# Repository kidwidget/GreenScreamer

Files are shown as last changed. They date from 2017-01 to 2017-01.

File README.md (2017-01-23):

# GreenScreamer
Guitar Effects Pedal
Uses Kicad
Has extra mounting holes for all capacitors, resistors, and diodes that effect tone. This is so you can solder in female pin headers to test various combinations before commiting. Bottom layer is only for ground plane. It can be omitted if you are making a single sided PCB. This will need jumper wires, refer to picture of finished product.

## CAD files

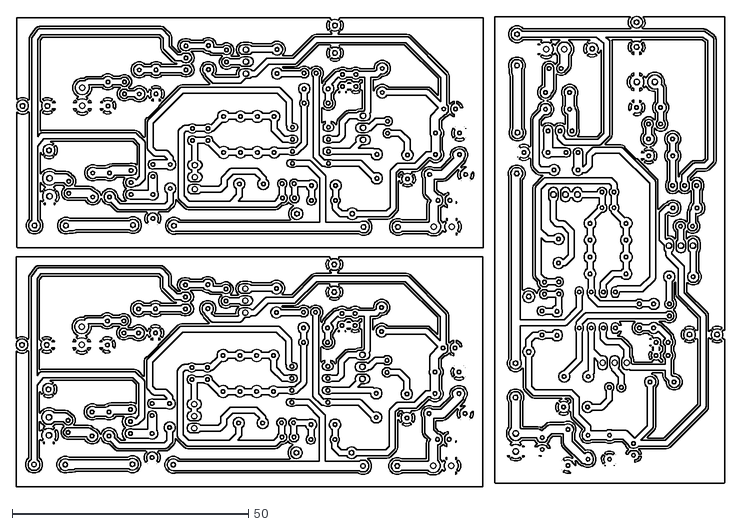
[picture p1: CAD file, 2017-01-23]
GreenScreamerGraphics/DXF/-B.Cu.dxf
149.9 x 99.5

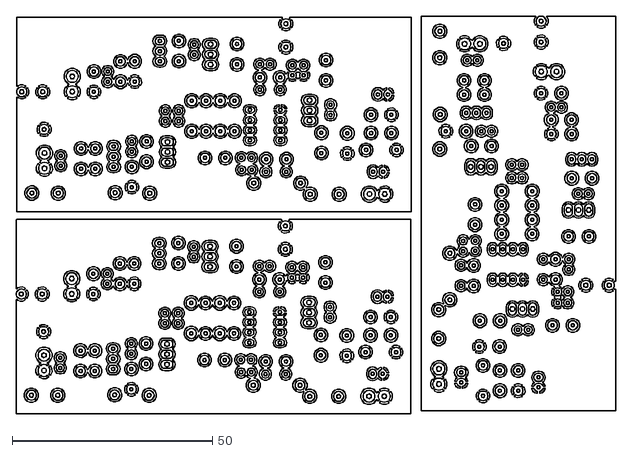
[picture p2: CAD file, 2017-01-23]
GreenScreamerGraphics/DXF/-F.Cu.dxf
149.9 x 99.5

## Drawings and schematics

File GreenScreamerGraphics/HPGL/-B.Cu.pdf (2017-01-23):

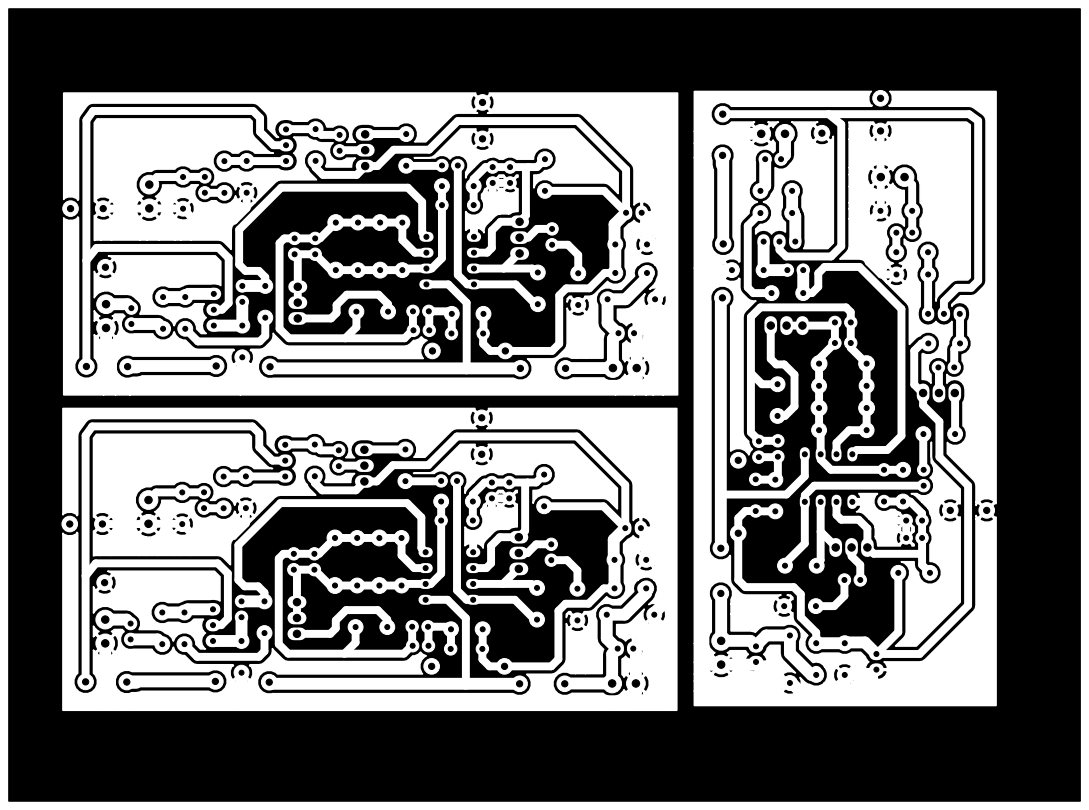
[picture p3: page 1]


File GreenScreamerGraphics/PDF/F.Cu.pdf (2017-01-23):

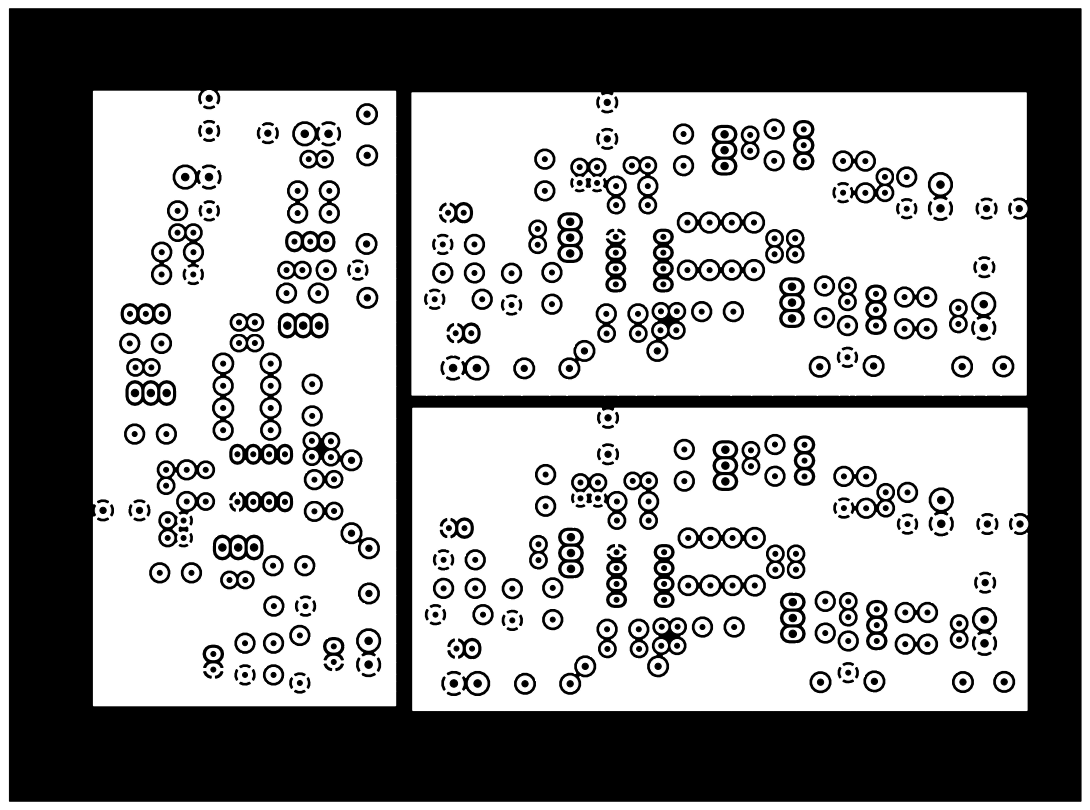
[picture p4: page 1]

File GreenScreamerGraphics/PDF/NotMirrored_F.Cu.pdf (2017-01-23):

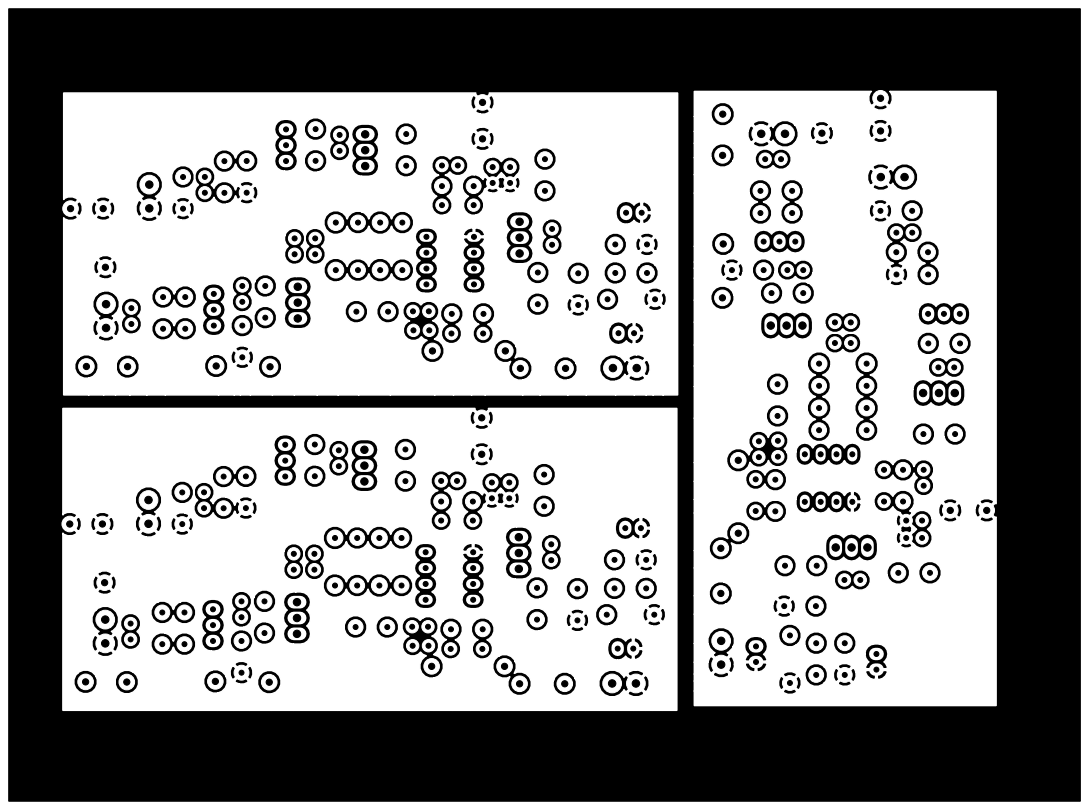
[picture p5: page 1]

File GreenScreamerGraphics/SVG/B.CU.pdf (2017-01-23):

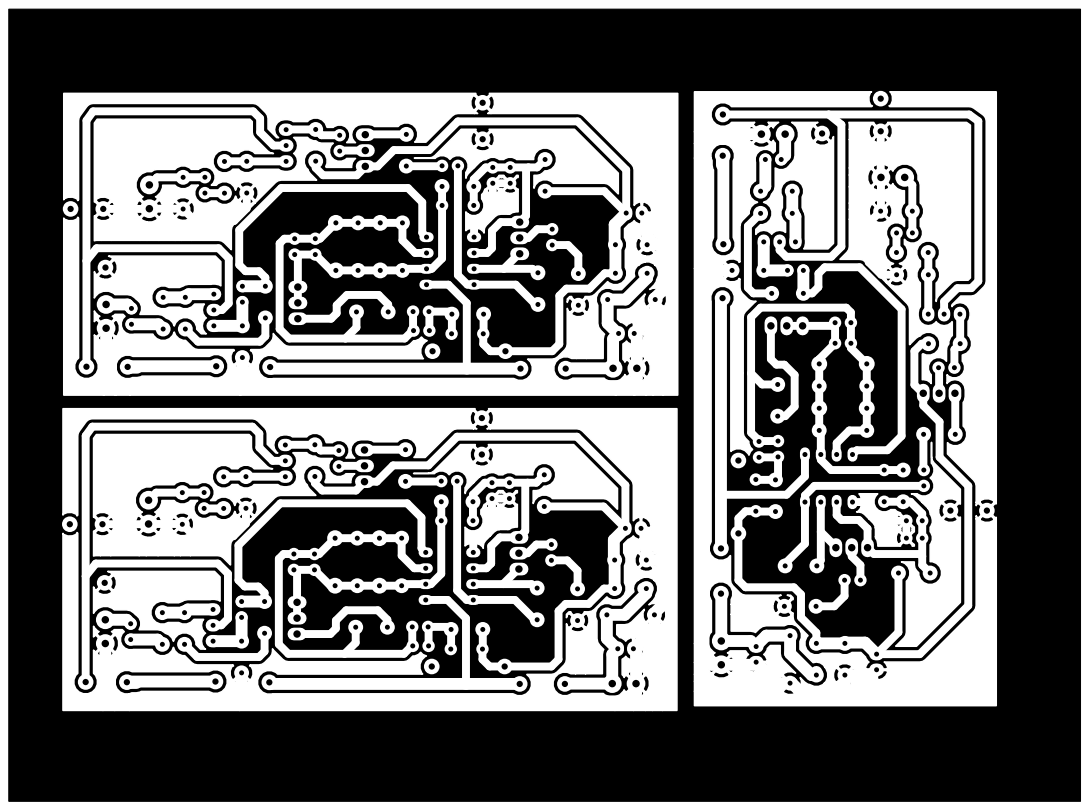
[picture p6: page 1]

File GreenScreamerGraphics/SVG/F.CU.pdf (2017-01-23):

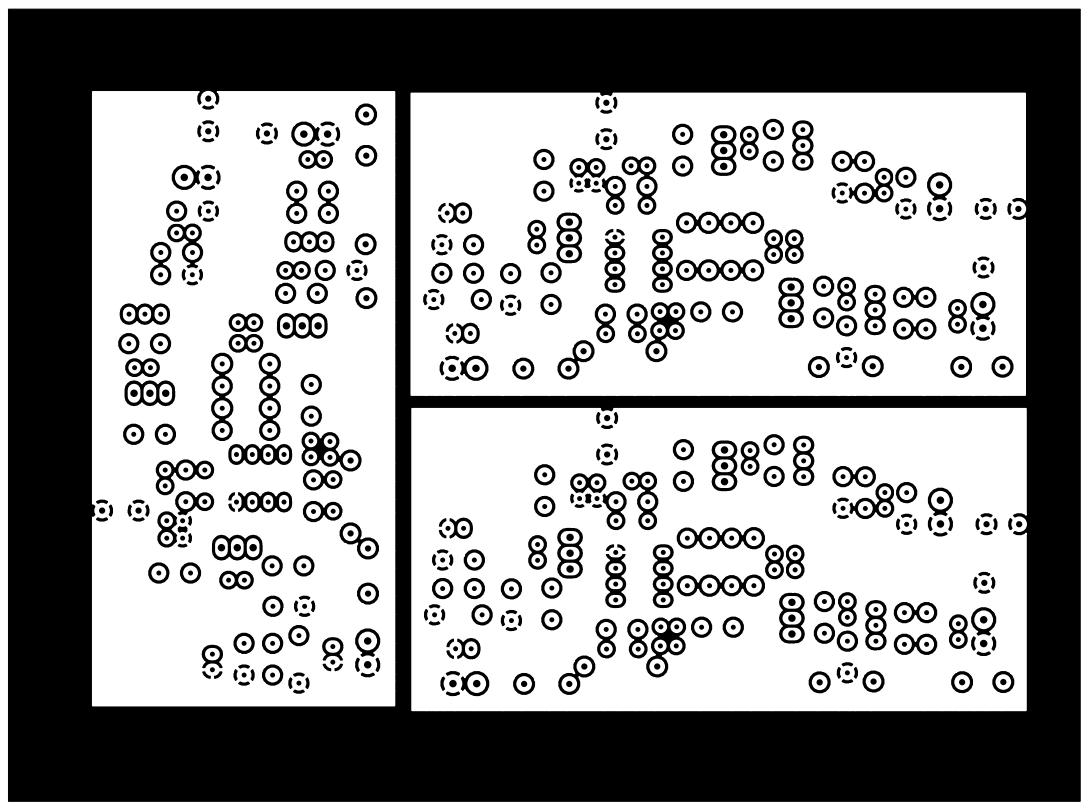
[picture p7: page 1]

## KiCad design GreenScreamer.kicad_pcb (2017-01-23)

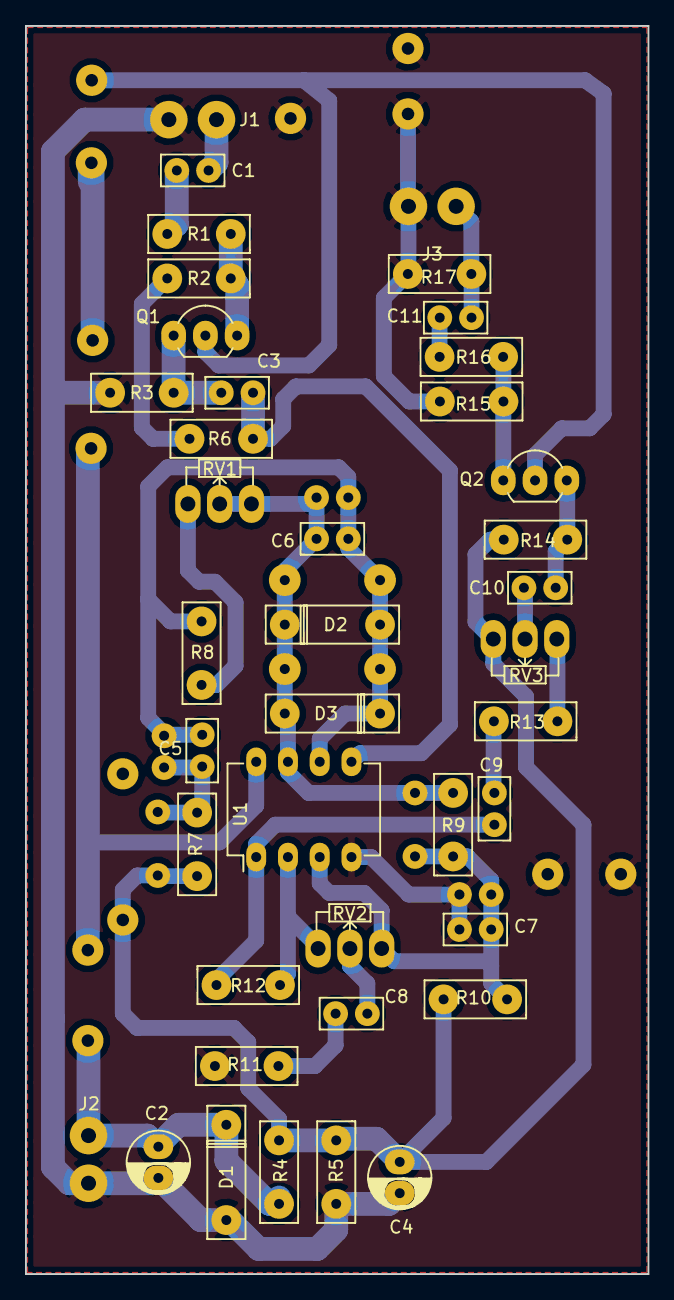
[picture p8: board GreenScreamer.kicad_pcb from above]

Board: 2 copper layers, 49.8 x 99.8 mm, 40 parts (0 on the bottom side), 24 nets.

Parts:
C1: .027uF; Capacitor1
C2: 100uF; C_Radial_D5_L6_P2.5
C3, C9: 1uF; Capacitor1
C4: 47uF; C_Radial_D5_L6_P2.5
C5: .047uF; Capacitor1
C6: 51pF; Capacitor1
C7, C8: .22uf Tant; Capacitor1
C10: .1uF; Capacitor1
C11: 10uF; Capacitor1
D1: 1N4003; diode3
D2, D3: 1N914; diode3
J1, J2, J3: JackMono; MonoJackRemote
Q1, Q2: KSC1518; TO-92_Inline_Wide_Oval
R1, R9, R12, R13: 1k; Resistor2
R2, R14: 510k; Resistor2
R3, R4, R5, R6, R10, R15, R17: 10k; Resistor2
R7: 4.7k; Resistor2
R8: 51k; Resistor2
R11: 220; Resistor2
R16: 100; Resistor2
RV1: 500k; Potentiometer_WirePads_Small_Oval
RV2: 20k; Potentiometer_WirePads_Small_Oval
RV3: 100k; Potentiometer_WirePads_Small_Oval
U1: JNR4558; DIP-8_W7.62mm_LongPads

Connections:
+9V: C2.1, D1.1, J2.1, Q1.2, Q2.2, R4.1, U1.8
/4v5: C4.1, R2.2, R4.2, R5.1, R6.2, R7.2, R10.2, R14.1, RV3.3
GNDREF: C2.2, C4.2, C7.2, D1.2, J1.2, J2.2, J3.2, R3.2, R5.2, R11.2, R15.1, R17.1, U1.4
unnamed: C1.1, R1.2
unnamed: C1.2, J1.1
unnamed: C3.1, R6.1, U1.5
unnamed: C3.2, Q1.1, R3.1
unnamed: C5.1, R7.1
unnamed: C5.2, C6.2, D2.2, D3.1, R8.2, U1.6
unnamed: C6.1, D2.1, D3.2, R9.2, RV1.2, RV1.3, U1.7
unnamed: C7.1, R9.1, R10.1, RV2.3, U1.3
unnamed: C8.1, RV2.2
unnamed: C8.2, R11.1
unnamed: C9.1, R13.2
unnamed: C9.2, R12.1, U1.1
unnamed: C10.1, Q2.3, R14.2
unnamed: C10.2, RV3.2
unnamed: C11.1, R16.2
unnamed: C11.2, J3.1, R17.2
unnamed: Q1.3, R1.1, R2.1
unnamed: Q2.1, R15.2, R16.1
unnamed: R8.1, RV1.1
unnamed: R12.2, RV2.1, U1.2
unnamed: R13.1, RV3.1
